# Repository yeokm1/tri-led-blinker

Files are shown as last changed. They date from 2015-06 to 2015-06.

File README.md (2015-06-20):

# tri-led-blinker

A "simple" blinking gift for somebody. Has On-Off switch and a button to change the order of blinking.

Blink orders:

1. Forward
2. Reverse
3. Twice forward
4. Twice reverse
5. All

##Software

1. Arduino 1.6.5 IDE
2. [Custom Lowpower library to support ATTiny85 by johnnie502](https://github.com/johnnie502/Low-Power/)

##Hardware

##Prototype

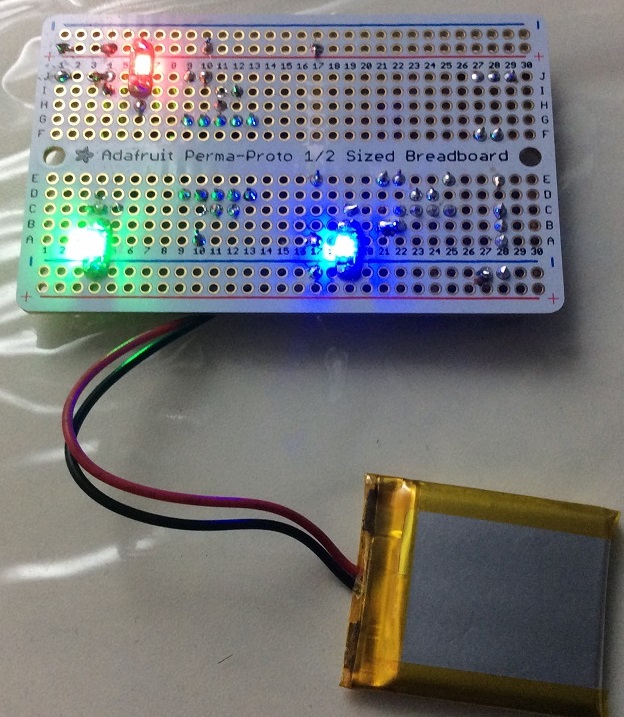
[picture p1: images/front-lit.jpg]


Front view with all LEDs lit

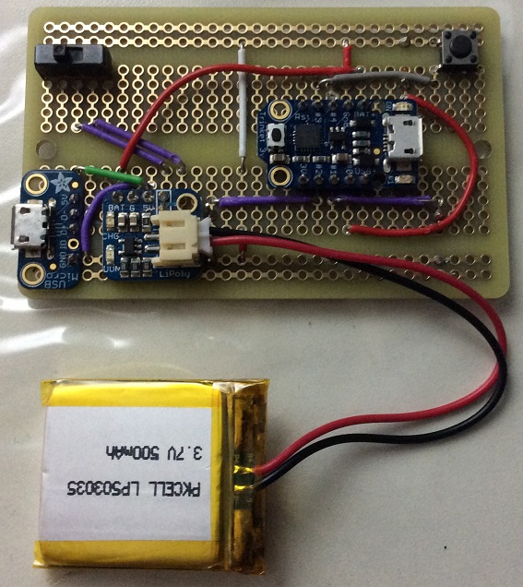
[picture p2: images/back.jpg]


Back view

###Demo video on Youtube

(https://www.youtube.com/watch?v=Z5MDIierKuw)

###Parts used that are different from PCB design
1. [Adafruit LED Sequin (Ruby Red)](https://www.adafruit.com/products/1755)
2. [Adafruit LED Sequin (Emerald Green)](https://www.adafruit.com/products/1756)
3. [Adafruit LED Sequin (Royal Blue)](https://www.adafruit.com/products/1757)
4. [Adafruit USB Micro-B Breakout Board](https://www.adafruit.com/products/1833)
5. [Adafruit Perma-Proto Half-sized Breadboard PCB - Single](https://www.adafruit.com/products/1609)

## Proposed PCB Design

###PCB Design software and addons used

1. Eagle 7.3.0: I use Standard but Light should still be able to open/modify the files.
2. Seeed OPL libraries: Button, Connector, Diode (in pcb libraries folder)
2. Seeedstudio Design Rule Check for 2 layers (in repo as `SeeedStudio_2layer_DRU_no_angle_20140221.dru`)
3. Seeed Gerber Generater 2-layer board (in repo as `Seeed_Gerber_Generater_2-layer.cam`)

###Schematic drawings

Images are exported from Eagle at 600dpi.

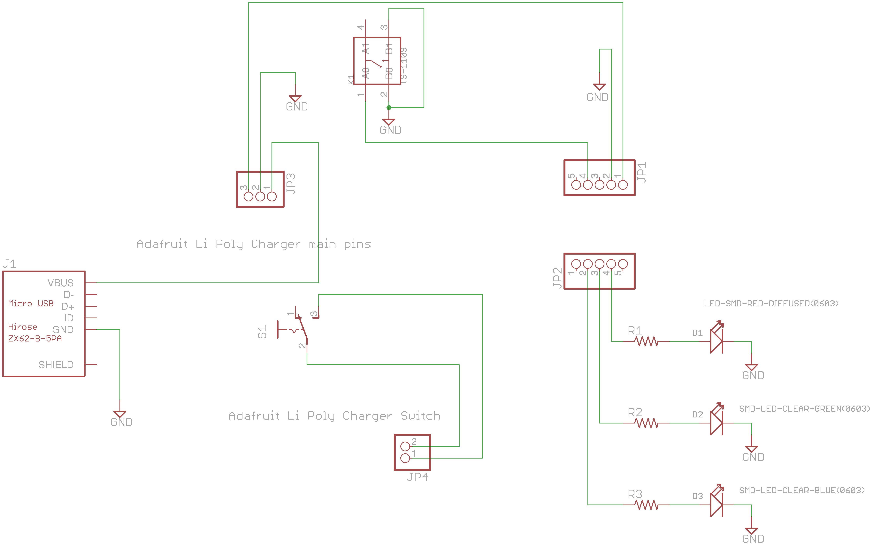
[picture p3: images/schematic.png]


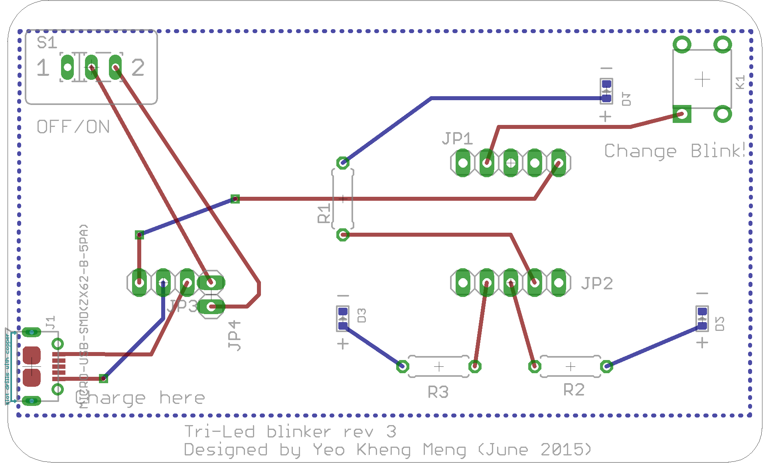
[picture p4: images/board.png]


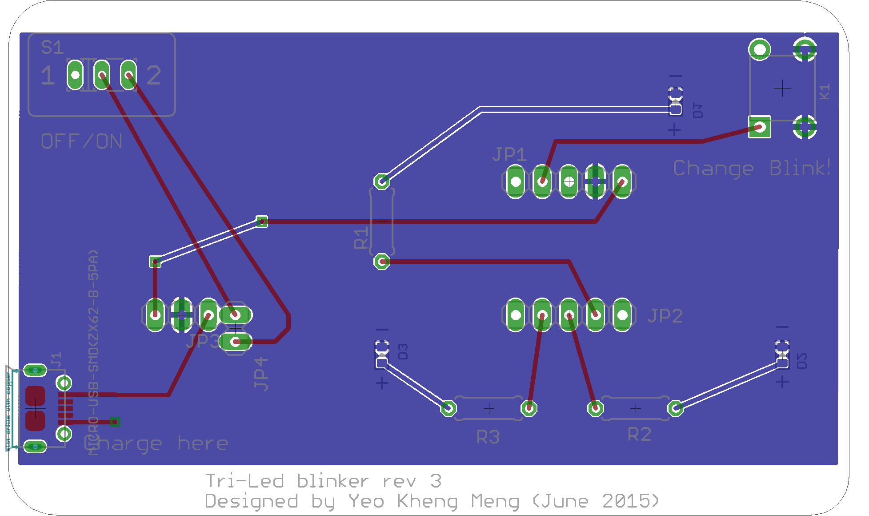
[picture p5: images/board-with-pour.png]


The copper pour is connected to ground

###Parts required

1. JP1 and JP2: Pin header stand-in for [Adafruit Trinket 3V](https://www.adafruit.com/products/1500)
2. J1: SMD Micro-USB connector: Seeed OPL part 3400150P1
3. S1: [SPDT slide switch from Adafruit](https://www.adafruit.com/products/805). Others will work too
4. K1: Push button: Seeed OPL part 3110040P1
5. JP3 and JP4: Pin header stand-in for [Adafruit Pro Trinket LiIon/LiPoly Backpack Add-On](https://www.adafruit.com/products/2124)
6. D1: 0603 SMD Diffused-Red LED 1.7V-2.2V, 25mA: Seeed OPL part 0330020P1
7. D2: 0603 SMD Clear-Green LED 2.75V-3.95V , 25mA: Seeed OPL part 0330010P1
8. D2: 0603 SMD Clear-Blue LED 2.5V-3.1V , 25mA: Seeed OPL part 0330060P1
9. R1: Through-hole resistor 0.25W for red LED : Undetermined
10. R2: Through-hole resistor 0.25W for green LED : Undetermined
11. R3: Through-hole resistor 0.25W for blue LED : Undetermined

###PCB fabrication

PCB fabrication is currently done by [Seeedstudio](https://www.seeedstudio.com/service/index.php?r=pcb) based on the following settings. Remember to consult the [order submission guidelines](http://support.seeedstudio.com/knowledgebase/articles/422482-fusion-pcb-order-submission-guidelines) before submitting. Use the provided Gerber generator to produce the Gerber files.

Seeedstudio requires the following gerber files to be zipped up for submission:

1. Top Layer: pcbname.GTL
2. Top Solder Mask: pcbname.GTS
3. Top Silkscreen: pcbname.GTO
4. Bottom Layer: pcbname.GBL
5. Bottom Solder Mask: pcbname.GBS
6. Bottom silkscreen: pcbname.GBO
7. Board Outline:pcbname.GML/GKO
8. Drills: pcbname.TXT
9. Inner Layer: pcbname.GL2(for 4 layer)
10. Inner Layer: pcbname.GL3(for 4 layer)

The zip file has been uploaded to the Releases section.

####My Fabrication Settings: 

1. Layer: 2
2. PCB Dimension: 5cm Max * 10cm Max
3. PCB Thickness: 1.2mm
4. PCB Qty: 10
5. PCB Color: Black (+US$20, expensive but I like Black)
6. Surface Finish: Hasl(Lead Free)
7. Copper weight: 1oz
8. Panalized PCBs: 1
9. Expedited Option: No
10. PCB Stencil: Unchecked

####PCB assembly:

Just use the provided `BOM File for Seeedstudio.csv`. I opted to do the assembly for only 5 pieces in case there are issues and I have to solder myself.

###Letters
I 3D-printed the letters based on the STL files obtained from [thingverse](http://www.thingiverse.com/thing:15198).

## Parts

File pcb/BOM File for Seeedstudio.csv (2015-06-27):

OPL SKU | Qty. | Parts
320010006 | 1 | J1
3110040P1 | 1 | K1
0330020P1 | 1 | D1
0330010P1 | 1 | D2
0330060P1 | 1 | D3

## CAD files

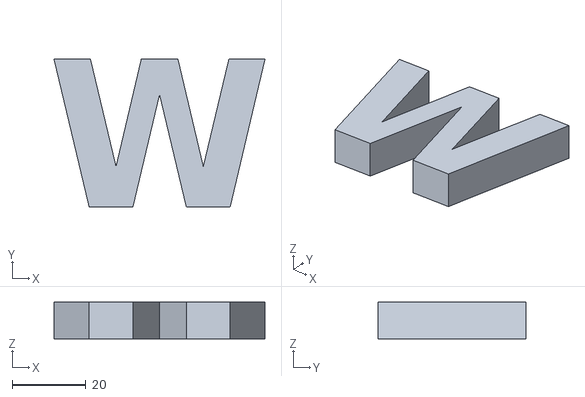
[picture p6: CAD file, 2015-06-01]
3d letters/Letter_W.stl
57.2 x 40.0 x 10.0

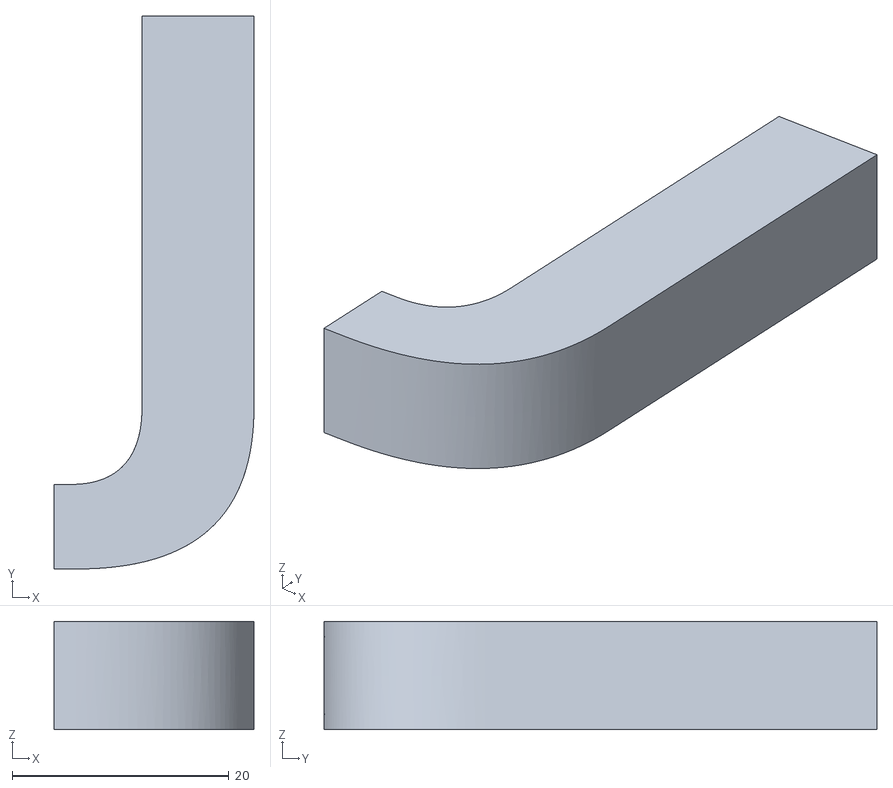
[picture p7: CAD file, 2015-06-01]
3d letters/Letter_J.stl
18.4 x 51.0 x 10.0

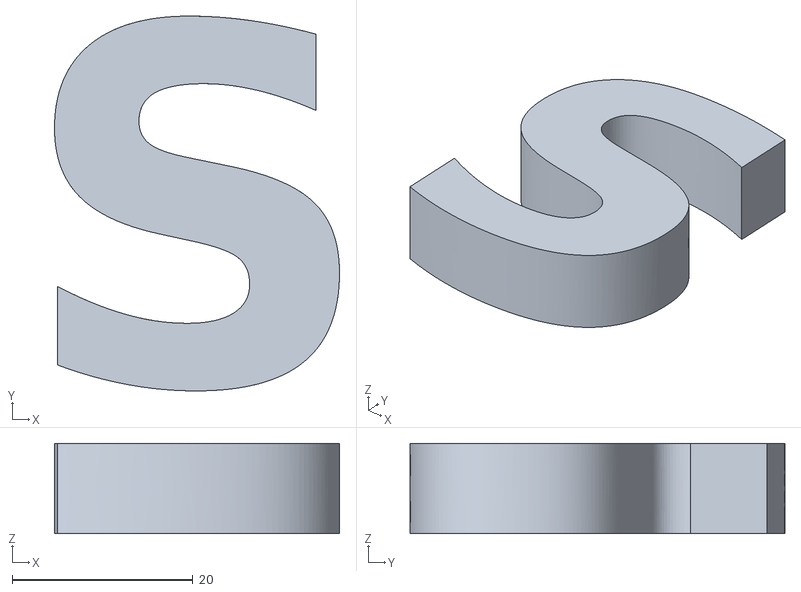
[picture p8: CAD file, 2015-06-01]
3d letters/Letter_S.stl
31.6 x 41.5 x 10.0

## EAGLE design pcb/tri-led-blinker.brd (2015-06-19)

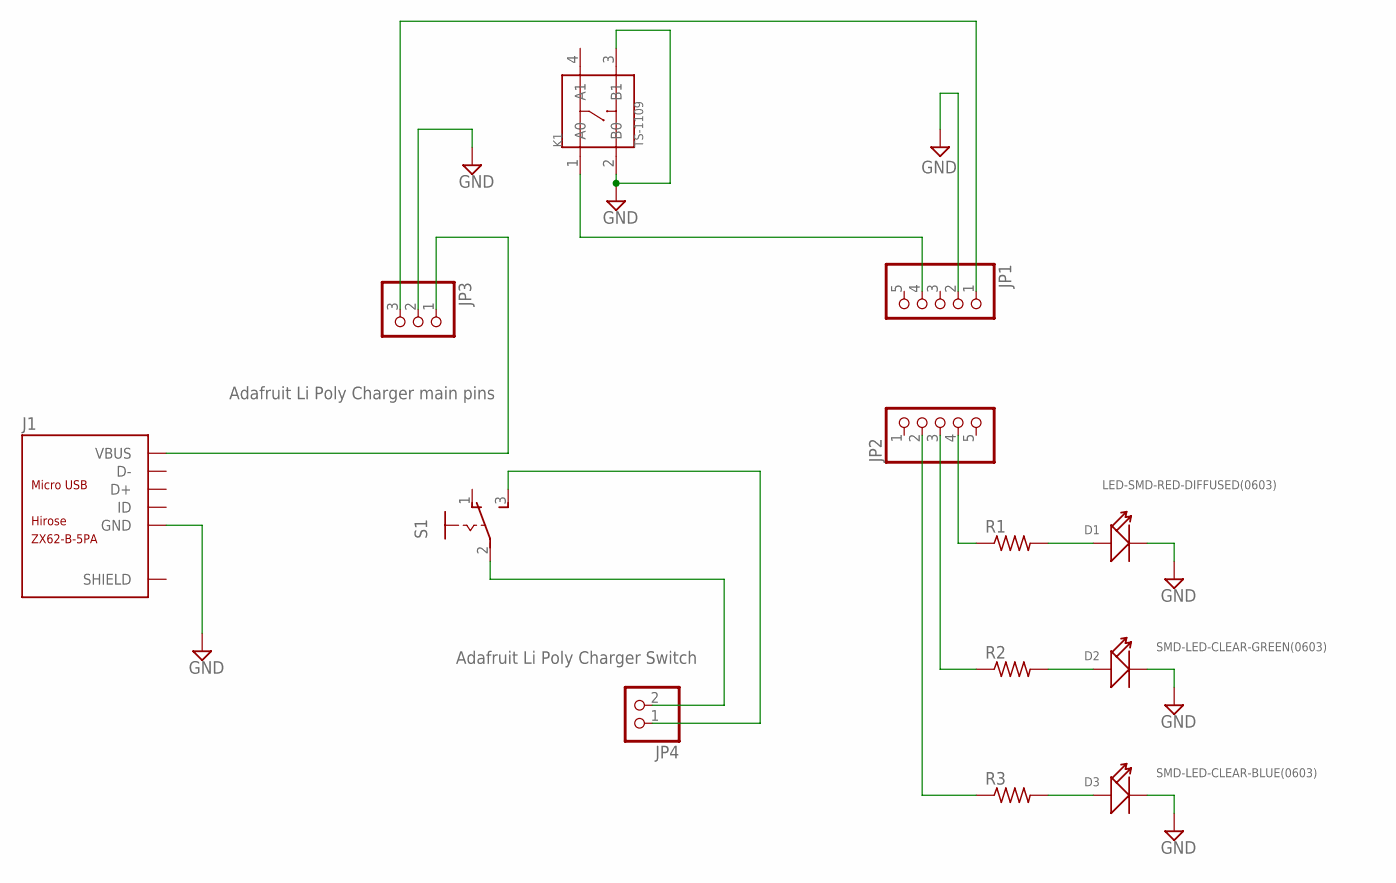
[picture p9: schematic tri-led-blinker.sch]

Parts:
D1: LED-SMD-RED-DIFFUSED(0603); LED-0603
D2: SMD-LED-CLEAR-GREEN(0603); LED-0603
D3: SMD-LED-CLEAR-BLUE(0603); LED-0603
J1: MICRO-USB-SMD(ZX62-B-5PA); MICRO-USB5+6P-SMD-0.65-AB
JP1, JP2: PINHD-1X5; 1X05
JP3: Adafruit Li Poly Charger main pins; 1X03
JP4: Adafruit Li Poly Charger Switch; 1X02
K1: TS-1109; SW4-6.0X6.0X5.0MM
R1, R2, R3: R-US_0207/7; 0207/7
S1: M251

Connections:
GND: D1.-, D2.-, D3.-, J1.5 (GND), JP1.2, JP3.2, K1.2 (B0), K1.3 (B1)
unnamed: D1.+, R1.2
unnamed: JP4.2, S1.2
unnamed: JP4.1, S1.3 (S)
unnamed: D2.+, R2.2
unnamed: JP1.4, K1.1 (A0)
unnamed: JP2.2, R3.1
unnamed: D3.+, R3.2
unnamed: JP2.4, R1.1
unnamed: JP1.1, JP3.3
unnamed: JP2.3, R2.1
VBUS: J1.1 (VBUS), JP3.1

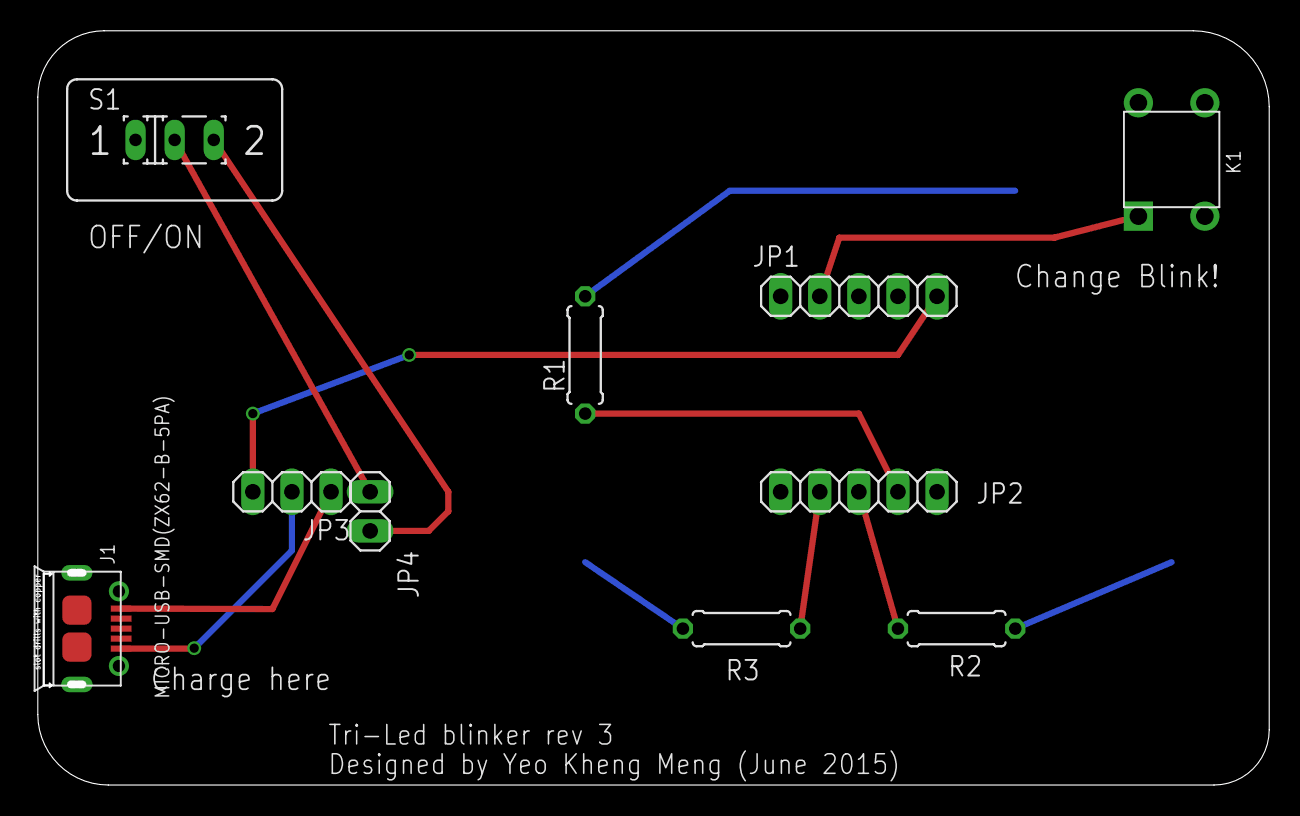
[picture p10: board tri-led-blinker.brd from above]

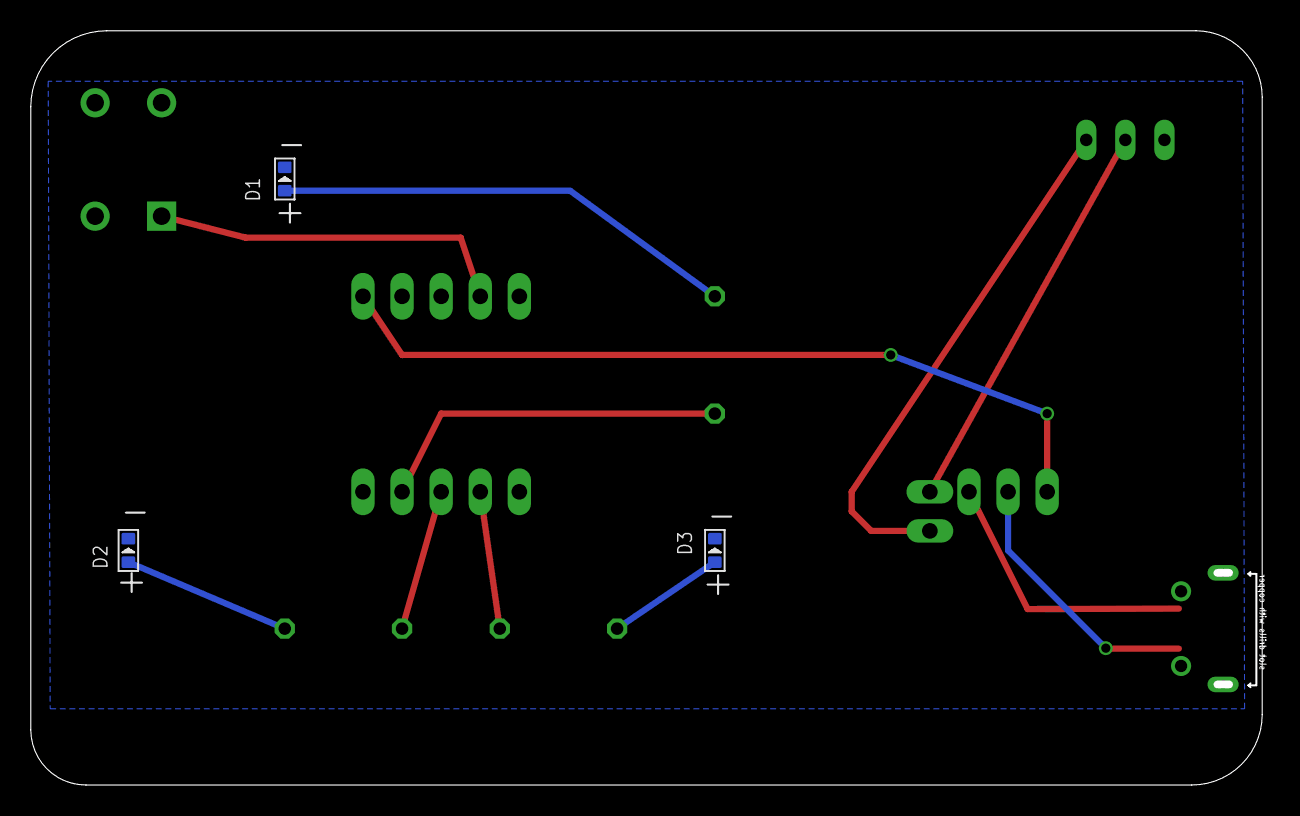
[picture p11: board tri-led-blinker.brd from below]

Board: 2 copper layers, 80.0 x 49.0 mm, 13 parts (3 on the bottom side), 12 nets.

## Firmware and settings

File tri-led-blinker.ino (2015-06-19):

#include "LowPower.h"
#define NUM_LETTERS 3

//Uncomment this if you want to skip the reverse states
//#define REDUCE_FUNCTION

#define PIN_L1 PB0
#define PIN_L2 PB1
#define PIN_L3 PB2
#define PIN_BUTTON PB3

//Accept only one button input every 0.3s
#define DEBOUNCE_TIME 300 //0.3s

#define DELAY_BETWEEN_LETTERS 750


typedef enum {
  STATE_FORWARD, STATE_REVERSE, STATE_BLINK_TWICE_FORWARD, STATE_BLINK_TWICE_BACKWARD, STATE_BLINK_ALL} 
BLINK_STATE ;
volatile BLINK_STATE blinkState = STATE_FORWARD;


const int PINS[NUM_LETTERS] = {PIN_L1, PIN_L2, PIN_L3};


int currentPinToLight = 0;

bool allCurrentlyOn = false;


//Initialise the last time the button is pressed
long buttonLastPressedTime = millis();

long timeLastBlink = millis();


int timesBlinkedAtOneSpot = 0;

void setup() {

  pinMode(PIN_BUTTON, INPUT);
  
  for(int currentPos = 0; currentPos < NUM_LETTERS; currentPos++){
    pinMode(PINS[currentPos], OUTPUT);
  }

}

void loop() {

  if(shouldProceedToNextBlink()){
  
    switch(blinkState){
      case STATE_FORWARD: blinkForward();
      break;
      case STATE_REVERSE: blinkReverse();
      break;
      case STATE_BLINK_TWICE_FORWARD: blinkTwiceForward();
      break;
      case STATE_BLINK_TWICE_BACKWARD: blinkTwiceBackward();
      break;
      case STATE_BLINK_ALL: blinkAll();
      break;
      default: blinkForward();
    }
   }
  
  
  if(isButtonPressed()){
    buttonPressed();
  }

  LowPower.powerSave(SLEEP_60MS, ADC_OFF, BOD_OFF, TIMER2_ON); 
}


bool isButtonPressed(){
  int buttonState = digitalRead(PIN_BUTTON);
  long currentTime = millis();
   
  //This code is to debounce the button input.
  if(buttonState == LOW && ((currentTime - buttonLastPressedTime) > DEBOUNCE_TIME)){
    buttonLastPressedTime = currentTime;
    return true;
  } else {
    return false;
  }
}

void blinkForward(){

  if(currentPinToLight >= NUM_LETTERS){
    currentPinToLight = 0;
  }
   
  onlyTurnOnThisLED(currentPinToLight);
   
  currentPinToLight++;

}



void blinkReverse(){

  if(currentPinToLight < 0){
    currentPinToLight = NUM_LETTERS - 1;
  }
   
  onlyTurnOnThisLED(currentPinToLight);
   
  currentPinToLight--;
}


void blinkTwiceForward(){
  if(currentPinToLight >= NUM_LETTERS){
    currentPinToLight = 0;
  }

  if(timesBlinkedAtOneSpot == 0){
      onlyTurnOnThisLED(currentPinToLight);
      timesBlinkedAtOneSpot++;
  } else if(timesBlinkedAtOneSpot == 1){
      writeToAllLeds(false);
      timesBlinkedAtOneSpot++;
  } else if(timesBlinkedAtOneSpot == 2){
      onlyTurnOnThisLED(currentPinToLight);
      timesBlinkedAtOneSpot++;
  } else {
    writeToAllLeds(false);
    timesBlinkedAtOneSpot = 0;
    currentPinToLight++;
  }
}

void blinkTwiceBackward(){
  if(currentPinToLight < 0){
    currentPinToLight = NUM_LETTERS - 1;
  }

  if(timesBlinkedAtOneSpot == 0){
      onlyTurnOnThisLED(currentPinToLight);
      timesBlinkedAtOneSpot++;
  } else if(timesBlinkedAtOneSpot == 1){
      writeToAllLeds(false);
      timesBlinkedAtOneSpot++;
  } else if(timesBlinkedAtOneSpot == 2){
      onlyTurnOnThisLED(currentPinToLight);
      timesBlinkedAtOneSpot++;
  } else {
    writeToAllLeds(false);
    timesBlinkedAtOneSpot = 0;
    currentPinToLight--;
  }
}

void blinkAll(){
  
  allCurrentlyOn = !allCurrentlyOn;

  int value = allCurrentlyOn ? HIGH : LOW;

  writeToAllLeds(value);
  
}

bool shouldProceedToNextBlink(){
  long currentTime = millis();
  

  if((currentTime - timeLastBlink) > DELAY_BETWEEN_LETTERS){
    timeLastBlink = currentTime;
    return true;
  }

  return false;
}

#ifdef REDUCE_FUNCTION

void buttonPressed(){
  switch(blinkState){
    case STATE_FORWARD: blinkState = STATE_BLINK_TWICE_FORWARD;
    break;
    case STATE_BLINK_TWICE_FORWARD: blinkState = STATE_BLINK_ALL;
    break;
    case STATE_BLINK_ALL : blinkState = STATE_FORWARD;
    break;
    default: blinkState = STATE_FORWARD;
  }
}

#else

void buttonPressed(){
  switch(blinkState){
    case STATE_FORWARD: blinkState = STATE_REVERSE;
    break;
    case STATE_REVERSE: blinkState = STATE_BLINK_TWICE_FORWARD;
    break;
    case STATE_BLINK_TWICE_FORWARD: blinkState = STATE_BLINK_TWICE_BACKWARD;
    break;
    case STATE_BLINK_TWICE_BACKWARD: blinkState = STATE_BLINK_ALL;
    break;
    case STATE_BLINK_ALL : blinkState = STATE_FORWARD;
    break;
    default: blinkState = STATE_FORWARD;
  }
}

#endif




void writeToAllLeds(int state){
  for(int currentPos = 0; currentPos < NUM_LETTERS; currentPos++){
    digitalWrite(PINS[currentPos], state);
  }
}

void onlyTurnOnThisLED(int pinPositionNumber){

  for(int currentPos = 0; currentPos < NUM_LETTERS; currentPos++){

    if(currentPos == pinPositionNumber){
      digitalWrite(PINS[currentPos], HIGH);
    } else {
      digitalWrite(PINS[currentPos], LOW);
    }  
  }
}

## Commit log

2015-06-01 update air wire usb ground
    [tri-led-blinker.brd]
2015-06-01 diode library
2015-06-01 added + and - labels to diode
    [tri-led-blinker.brd]
2015-06-01 bom file
    [BOM File for Seeedstudio.csv]
2015-06-01 shift resistor r1 a bit to the left
    [tri-led-blinker.brd]
2015-06-01 schematic size
    [tri-led-blinker.sch]
2015-06-01 seedstudio bom
    [BOM File for Seeedstudio.csv]
2015-06-03 revision 2 add date
    [tri-led-blinker.brd]
2015-06-19 change button input pin to PB3
    [tri-led-blinker.brd, tri-led-blinker.sch]
2015-06-19 use modified low power library
2015-06-19 up rev to 3.
    [tri-led-blinker.brd]
2015-06-19 ability to skip reverse states using #ifdef
    [tri-led-blinker.ino]
2015-06-27 change 320010015-SMD to 320010006-DIP
    [BOM File for Seeedstudio.csv]
